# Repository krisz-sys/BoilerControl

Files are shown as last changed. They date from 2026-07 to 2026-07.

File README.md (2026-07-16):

How it works?<br><br>
The ESP8266 runs a web server that displays various data.
The microcontroller turns on the boiler if:

The slider is triggered by the user

The time schedule is active

The user can set the time schedule via the web interface.
The microcontroller reads the value of a DHT11 temperature sensor from port D7 (GPIO13), and the boiler command is handled by port D5 (GPIO14).
The temperature reading is for informational purposes only.

You can access the web server by entering the IP address into your browser: http://192.168.1.223/ . <br>
Additionally, you need to configure the WiFi SSID and password.

You can see the circuit schematic below:



Here is the PCB layout:


<br><br>

You can find the AutoCAD Eagle design files as HeaterController_PCB.

If the web server is live, you should see the following view. The most important elements are the slider, the temperature value, and the time schedule table:
<br>


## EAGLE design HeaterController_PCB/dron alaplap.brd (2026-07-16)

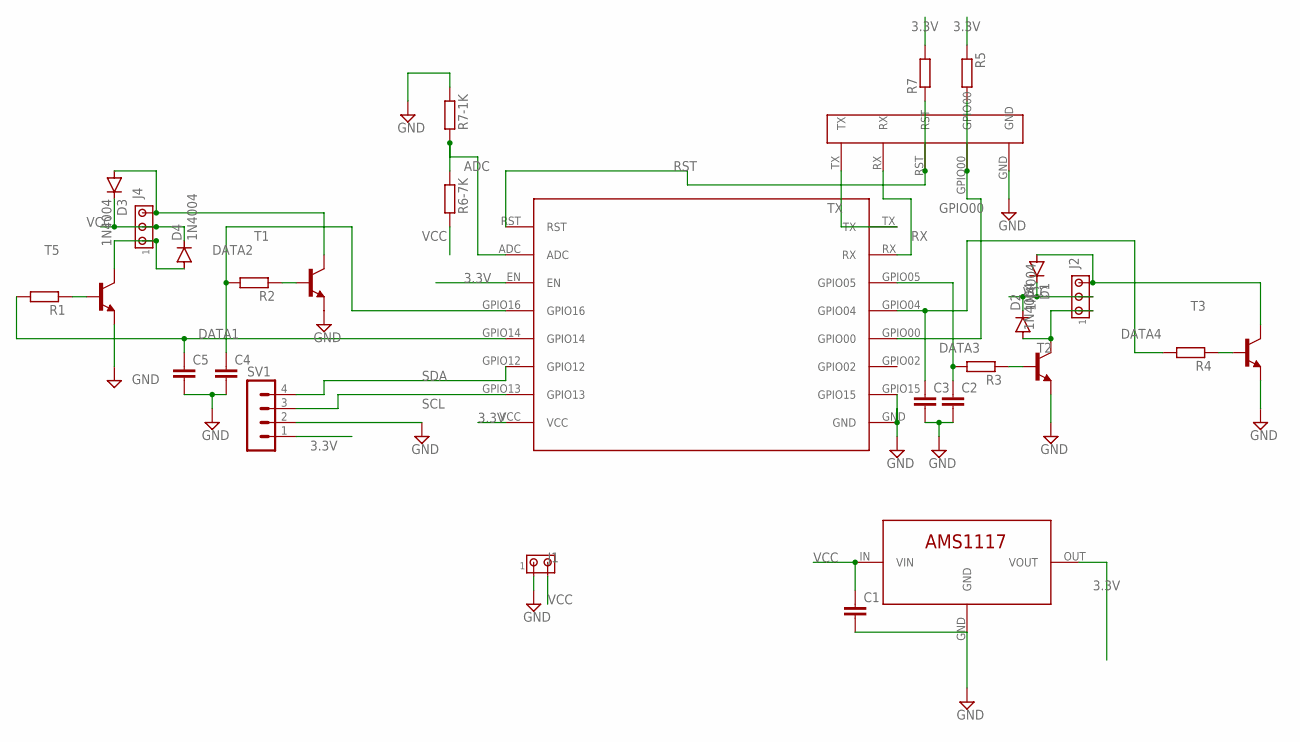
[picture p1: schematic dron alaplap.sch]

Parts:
C1: C-EU025-050X050; C025-050X050
C2, C3, C4: C-EU025-030X050; C025-030X050
C5: C-EU050-025X075; C050-025X075
D1, D2, D3, D4: 1N4004; DO41-10
J1: MTA02-156; 1X2MTA
J2, J4: MTA03-156; 1X3MTA
R1, R2, R3, R4, R5, R6-7K, R7-1K: R-EU_0207/12; 0207/12
R7: R-EU_0207/15; 0207/15
SV1: MA04-1
T1, T2, T3, T5: 2N2222-NPN-TO92-EBC; TO92-EBC
U$1: AMS1117
U$2: ESP8266
U$3: PIN

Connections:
3.3V: R5.1, R7.2, SV1.1, U$1.OUT (VOUT), U$2.EN, U$2.VCC
ADC: R6-7K.1, R7-1K.2, U$2.ADC
DATA1: C5.1, R1.2, U$2.GPIO14
DATA2: C4.1, R2.2, U$2.GPIO16
DATA3: C2.1, R3.2, U$2.GPIO05
DATA4: C3.1, R4.2, U$2.GPIO04
GND: C1.2, C2.2, C3.2, C4.2, C5.2, J1.1, R7-1K.1, SV1.2, T1.E, T2.E, T3.E, T5.E, U$1.GND, U$2.GND, U$2.GPIO15, U$3.GND
GPIO00: R5.2, U$2.GPIO00, U$3.GPIO00
unnamed: D4.A, J4.1, T5.C
unnamed: D2.A, J2.1, T2.C
unnamed: R1.1, T5.B
unnamed: D3.A, J4.3, T1.C
unnamed: R2.1, T1.B
unnamed: R3.1, T2.B
unnamed: D1.A, J2.3, T3.C
unnamed: R4.1, T3.B
RST: R7.1, U$2.RST, U$3.RST
RX: U$2.RX, U$3.RX
SCL: SV1.3, U$2.GPIO13
SDA: SV1.4, U$2.GPIO12
TX: U$2.TX, U$3.TX
VCC: C1.1, D1.C, D2.C, D3.C, D4.C, J1.2, J2.2, J4.2, R6-7K.2, U$1.IN (VIN)

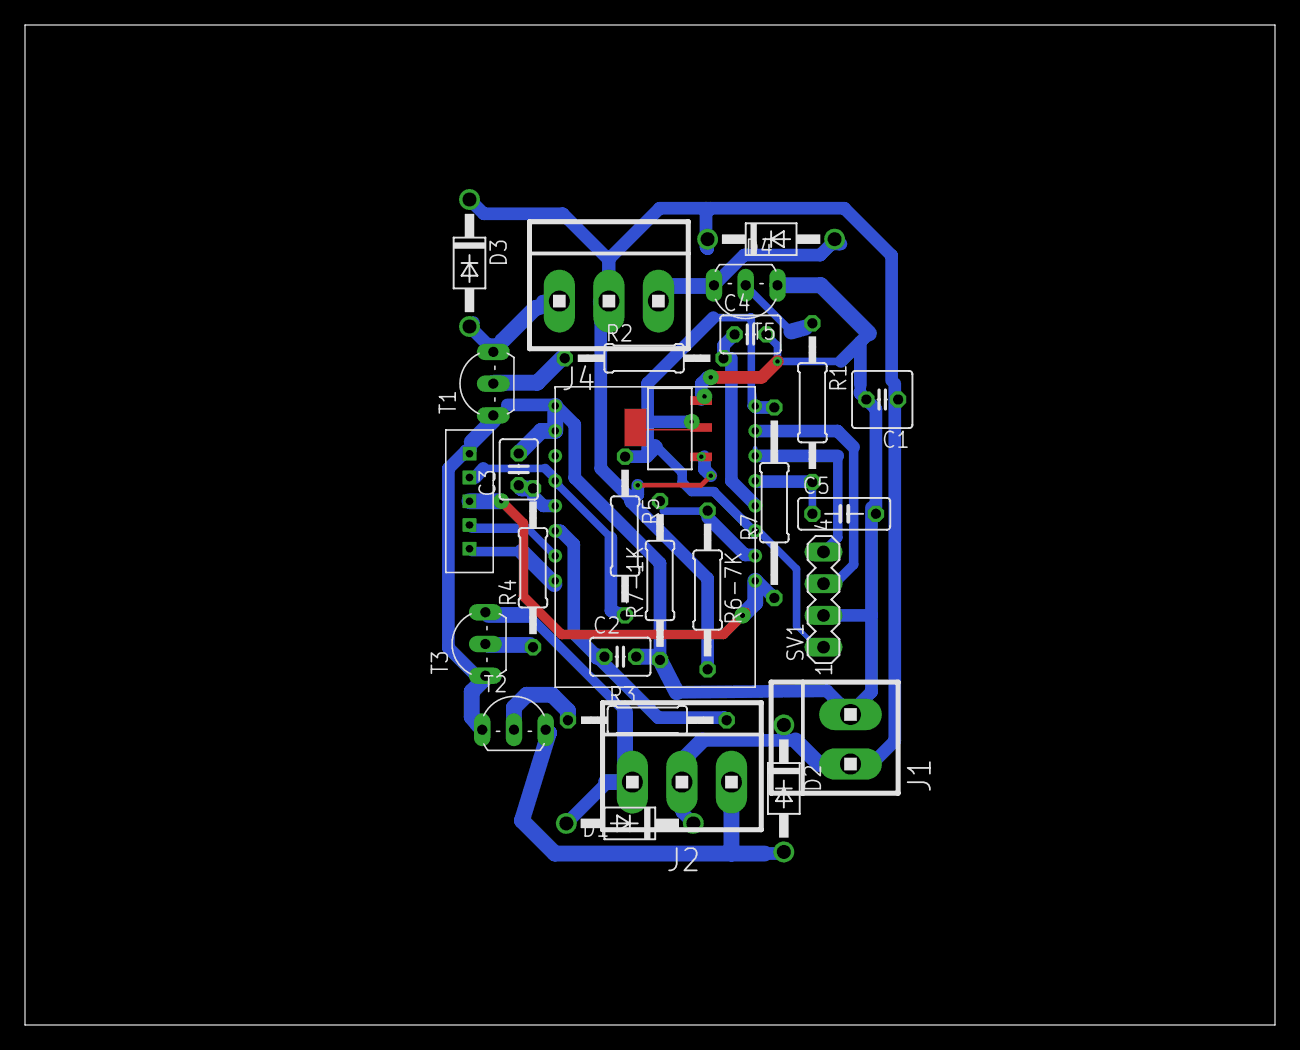
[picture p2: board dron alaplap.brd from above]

Board: 2 copper layers, 100.0 x 80.0 mm, 28 parts (0 on the bottom side), 22 nets.

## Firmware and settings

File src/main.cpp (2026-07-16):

#include <ESP8266WiFi.h>
#include <WiFiUdp.h>
#include <ESP_EEPROM.h>
#include <string.h>
#include <iostream>
#include <sstream>
#include <String.h>
#include "DHT.h"
#include <ArduinoOTA.h>
#include <ESPAsyncWebServer.h>
#include <ESP8266mDNS.h>
#include <time.h>

#include "index.h"
// -------------------------------------- time.h
const char* TZ_INFO = "EET-2EEST,M3.5.0,M10.5.0/3";

// -------------------------------------- NTP server

String formattedDate;
String dayStamp;
String timeStamp;
long date_check_timer;
//--------------------------------------  UDP communication
unsigned int localUdpPort = 9800;
char incomingPacket[255];  // buffer for incoming packets
char respond[255];
char  replyPacket[] = "Hi there! Got the message :-)";  // a reply string to send back
WiFiUDP Udp;
//char* remoteIp="";
String remoteIp="";
//--------------------------------------- temp, humidity 
#define DHTPIN D7              // GPIO13
#define DHTTYPE DHT11
DHT dht(DHTPIN, DHTTYPE);
float humidity=-10;
float temperature=-10;
// --------------------------------------- comm protocol

#define COMM_ERR 56
#define TEMP_REQUEST 39
#define TEMP_FLAG 40
#define HUM_REQUEST 41
#define HUM_FLAG 42
#define TEMP_SENSOR_ERROR 55
#define MSG_RECEIVED 65
//#define SET_LED 66
#define HEATER_ON 60                                  // turn ON theheater for x minutes
#define HEATER_REQUEST 61                             
#define HEATER_REMAINING 62                           // remaining time when the heater is ON
#define HUM_SENSOR_ERR 101                // the humidity sensor is damaged or don t works
#define BOSS 50
#define ADD_TSCH 51
#define ADD_TSCH_CONF 52
#define REMOVE_TSCH 53
#define REMOVE_TSCH_CONF 54
#define REMOVE_TSCH_NCONF 59
#define GET_TSCHS 57
#define SEND_TSCHS 58



//---------------------------------------- Heater
#define HEATER D5                             // GPIO14
//#define HEATER D1                             // GPIO05
bool ledSPMode=true;                       // false => led SP from the POT,       true => led SP from the sender
int lastSample=0;
bool firstStart=true;

//----------------------------------------wifi

//const char *ssid = "BV";          //Enter your wifi SSID
const char *ssid = "yourSSID";
const char *password = "yourPassword";        //Enter your wifi Password
IPAddress local_IP(192, 168, 1, 223);       // a telefonba ezt az ip-t kell beírni
//IPAddress local_IP(192, 168, 1, 223);
IPAddress gateway(192, 168, 1,1);
IPAddress subnet(255, 255, 255, 0);
IPAddress primaryDNS(8, 8, 8, 8);           //optional
IPAddress secondaryDNS(8, 8, 4, 4);

#define debug(x) Serial.print(x)
#define debugln(x) Serial.println(x)

long reconnect_period=120*1000;
long reconnectTimer;
long universalTimer;                        // call the other functionalitys every 100 ms

long testTimer;

long heaterCounter=0;                           // counts down every 3000ms until 0
long heaterTimer;
long heaterHandlerPeriod=3000;
long tempSamplePeriod=30000;

int TSCH_array[20][3];
int TSCH_len=0;
int currentTime=0;           // current time in minutes
long checkTSCHTimer;
long  tempSampleTimer;

AsyncWebServer server1(80);
AsyncWebSocket ws("/ws");  // WebSocket endpoint

// Function to send value updates to clients
void notifyClients(int heaterVal, float temp) {

  String finalString=String(heaterVal)+", "+String(temperature,1);

  for(int i=0;i<3;++i){
    finalString+=", ";
    int hour=TSCH_array[i][0];
    int min=TSCH_array[i][1];
    int time=TSCH_array[i][2];
    
    if(hour<10){
      finalString+="0";
    }
    finalString+=String(hour)+":";
    if(min<10){
      finalString+="0";
    }
    finalString+=String(min)+", "+String(time);
  }
  
  ws.textAll(finalString);  // send value to all connected clients
}

// Handle incoming WebSocket messages (optional)
void onWebSocketMessage(void *arg, uint8_t *data, size_t len) {
  AwsFrameInfo *info = (AwsFrameInfo*)arg;

  if (info->final && info->index == 0 && info->opcode == WS_TEXT) {

    // Safe copy
    char message[len + 1];
    memcpy(message, data, len);
    message[len] = 0;

    String msg = String(message);
    Serial.println("Received: " + msg);

    // Expecting message like: "Slider: 234"
    String prefix = "Slider: ";
    if (msg.startsWith(prefix)) {
      String sliderVal = msg.substring(prefix.length());

      heaterCounter = sliderVal.toInt();
      if (heaterCounter > 0) {
        digitalWrite(HEATER, HIGH);
      }

      Serial.println("Parsed slider value: " + sliderVal);
    }

    prefix = "Button: ";

    if (msg.startsWith(prefix)) {
      String buttonVal = msg.substring(prefix.length());
      Serial.println("Button value: " + buttonVal);
    }


    
    if(msg.startsWith("TS") && msg.charAt(4)=='T'){
        prefix=msg.substring(0,7);
        int index=int(msg.charAt(2)-'0')-1;

      if (msg.startsWith(prefix)) {
        String TS1_Tval = msg.substring(prefix.length());
        int time=atoi(TS1_Tval.c_str());
        TSCH_array[index][2]=time;
        EEPROM.write(index*3+3, TSCH_array[index][2]);
        EEPROM.commit();
      }
    }
    

    if(msg.startsWith("TS") && msg.charAt(4)=='H'){
      prefix=msg.substring(0,7);
      int index=int(msg.charAt(2)-'0')-1;

      if (msg.startsWith(prefix)) {
        String TS1_Hval = msg.substring(prefix.length());
        String hour=TS1_Hval.substring(0,2);
        String minute=TS1_Hval.substring(3,5);

        TSCH_array[index][0]=atoi(hour.c_str());
        TSCH_array[index][1]=atoi(minute.c_str());
        EEPROM.write(index*3+1, TSCH_array[index][0]);
        EEPROM.write(index*3+2, TSCH_array[index][1]);
        EEPROM.commit();
      }
    }


  }
}

void onWebSocketEvent(AsyncWebSocket *server, AsyncWebSocketClient *client, 
                      AwsEventType type, void *arg, uint8_t *data, size_t len) {
  if (type == WS_EVT_CONNECT) {
    Serial.printf("Client #%u connected\n", client->id());
  } else if (type == WS_EVT_DISCONNECT) {
    Serial.printf("Client #%u disconnected\n", client->id());
  } else if (type == WS_EVT_DATA) {
    onWebSocketMessage(arg, data, len);
  }
}

String sliderValue = "0";
bool startMeasuring=false;


void connect2Wifi(int);
int receiveUDP();
void decodeAndBuildRespond();
void getTime();
int receiveUDP();
void sendUDP();
void readHumAndTemp();
bool temp2bytes(char*);
void turnON(int);
String processor(const String& var);
void temp1Request(AsyncWebServerRequest *request);
void sliderRequest(AsyncWebServerRequest *request);

void setup() {
  EEPROM.begin(512);
  Serial.begin(115200);
  
  dht.begin();
  pinMode(HEATER,OUTPUT);


  if (!WiFi.config(local_IP, gateway, subnet, primaryDNS, secondaryDNS)) {
    Serial.println("STA Failed to configure");
  }
  
  Serial.printf("Connecting to %s ", ssid);
  WiFi.mode(WIFI_STA);
  WiFi.begin(ssid, password); //Connect to wifi
  //WiFi.begin(ssid); //Connect to wifi
  connect2Wifi(200);

  Udp.begin(localUdpPort);

  reconnectTimer=millis();
  date_check_timer=millis();
  universalTimer=millis();
  heaterTimer=millis();
  checkTSCHTimer=millis();
  testTimer=millis();
  tempSampleTimer=millis();

  
  //TSCH_len=EEPROM.read(0);
  TSCH_len=4;
  for(int i=0;i<TSCH_len;++i){
    TSCH_array[i][0]=EEPROM.read(i*3+1);
    TSCH_array[i][1]=EEPROM.read(i*3+2);
    TSCH_array[i][2]=EEPROM.read(i*3+3);
  }
  // ---------------------------------- webserver

  server1.on("/", HTTP_GET, [](AsyncWebServerRequest *request){
    request->send_P(200, "text/html; charset=utf-8",index_html);
  });
  ws.onEvent(onWebSocketEvent);
  server1.addHandler(&ws);
  server1.begin();

    //---------------------------------- OTA

// Port defaults to 8266
  // ArduinoOTA.setPort(8266);

  // Hostname defaults to esp8266-[ChipID]
   ArduinoOTA.setHostname("ESP8266-Boiler controller");

  // No authentication by default
  ArduinoOTA.setPassword("admin");

  // Password can be set with it's md5 value as well
  // MD5(admin) = 21232f297a57a5a743894a0e4a801fc3
  // ArduinoOTA.setPasswordHash("21232f297a57a5a743894a0e4a801fc3");

  ArduinoOTA.onStart([]() {
    String type;
    if (ArduinoOTA.getCommand() == U_FLASH) {
      type = "sketch";
    } else {  // U_FS
      type = "filesystem";
    }

    // NOTE: if updating FS this would be the place to unmount FS using FS.end()
    Serial.println("Start updating " + type);
  });
  ArduinoOTA.onEnd([]() {
    Serial.println("\nEnd");
  });
  ArduinoOTA.onProgress([](unsigned int progress, unsigned int total) {
    Serial.printf("Progress: %u%%\r", (progress / (total / 100)));
  });
  ArduinoOTA.onError([](ota_error_t error) {
    Serial.printf("Error[%u]: ", error);
    if (error == OTA_AUTH_ERROR) {
      Serial.println("Auth Failed");
    } else if (error == OTA_BEGIN_ERROR) {
      Serial.println("Begin Failed");
    } else if (error == OTA_CONNECT_ERROR) {
      Serial.println("Connect Failed");
    } else if (error == OTA_RECEIVE_ERROR) {
      Serial.println("Receive Failed");
    } else if (error == OTA_END_ERROR) {
      Serial.println("End Failed");
    }
  });
  ArduinoOTA.begin();

  if (MDNS.begin("boilercontrol")) {
    Serial.println("mDNS responder started");
  }

  // ------------------ time.h

  configTime(0, 0, "pool.ntp.org", "time.nist.gov");
  
  // Időzóna érvényesítése
  setenv("TZ", TZ_INFO, 1);
  tzset();
}


String processor(const String& var){
  //Serial.println(var);
  if (var == "SLIDERVALUE"){
    return sliderValue;
  }
  return String();
}

void temp1Request(AsyncWebServerRequest *request){
      startMeasuring=true;
      //readHumAndTemp();
      request->send(200, "text/plain", String(temperature,1));          // sends with precision 1
}

void sliderRequest(AsyncWebServerRequest *request) {
  request->send(200, "text/plain", String(heaterCounter,0));
    
  }



void checkTSCH(){
  for(int i=0;i<TSCH_len;++i){
    int targetTime=60*((int)TSCH_array[i][0])+(int)TSCH_array[i][1];            // calculating the minutes => hours*60+minutes
    if(targetTime==currentTime){                                                // starting 
      turnON((int)TSCH_array[i][2]);
      debug("match: ");
      debugln(heaterCounter);
    }
  }
}

void heaterHandler(){

  if(heaterCounter>=0){
    heaterCounter--;
  }
  if(heaterCounter<0){
    digitalWrite(HEATER,0);
  }
}

void connect2Wifi(int max_attempts){
  int i=0;
  while (WiFi.status() != WL_CONNECTED)
  {
    delay(50);
    Serial.print(".");
    if(i>=max_attempts){
      break;
    }
    i++;
  }
  debugln("");
  debug("localIP: ");
  debugln(WiFi.localIP());
}


void decodeAndBuildRespond(){
  //debugln("decoding: ");
  for(int i=1;i<(int)incomingPacket[0];++i){
    debug((int)incomingPacket[i]);
    debug(" ");
  }
  //debugln("");
  int i=0;                    // counter of the receiver packet
  int j=1;              // counter of the respond packet
  int len=incomingPacket[i++];
  //char respond[50];
  //debug("len: ");
  //debugln(len);
  while(1){
    if(i>=len){
      break;
    }
    byte b=(byte)incomingPacket[i++];
    //debugln(b);
    if(b==TEMP_REQUEST){
      readHumAndTemp();
      char tempbytes[2];
      respond[j++]=TEMP_FLAG;
      if(temp2bytes(tempbytes)){
        respond[j++]=tempbytes[0];
        respond[j++]=tempbytes[1];
      }
      else{
        respond[j++]=TEMP_SENSOR_ERROR;
        respond[j++]=TEMP_SENSOR_ERROR;
      }
    }
    if(b==HUM_REQUEST){
      readHumAndTemp();
      respond[j++]=HUM_FLAG;
      if(humidity!=-10){
        respond[j++]=humidity;
      }
      else{
        respond[j++]=HUM_SENSOR_ERR;
      }
    }
    if(b==HEATER_ON){
      //heaterCounter=incomingPacket[i++];
      turnON(((int)incomingPacket[i++])-1);
      if(heaterCounter<=1){
        heaterCounter=0;
        digitalWrite(HEATER,0);
      }

    }
    if(b==HEATER_REQUEST){
      respond[j++]=HEATER_REMAINING;
      respond[j++]=(byte)(heaterCounter/(60000/heaterHandlerPeriod)+1);
    }
    if(b==ADD_TSCH){
      TSCH_array[TSCH_len][0]=(int)(incomingPacket[i++])-1;
      TSCH_array[TSCH_len][1]=(int)(incomingPacket[i++])-1;
      TSCH_array[TSCH_len][2]=(int)(incomingPacket[i++])-1;
      EEPROM.write(TSCH_len*3+1, TSCH_array[TSCH_len][0]);
      EEPROM.write(TSCH_len*3+2, TSCH_array[TSCH_len][1]);
      EEPROM.write(TSCH_len*3+3, TSCH_array[TSCH_len][2]);
      TSCH_len++;
      EEPROM.write(0, TSCH_len);
      EEPROM.commit();
      respond[j++]=ADD_TSCH_CONF;
    }
    if(b==REMOVE_TSCH){
      int index=(int)incomingPacket[i++]-1;
      if(index>=0 && index<TSCH_len){
        respond[j++]=REMOVE_TSCH_CONF;
        for (int k=index;k<TSCH_len-1;++k){
          TSCH_array[k][0]=TSCH_array[k+1][0];
          TSCH_array[k][1]=TSCH_array[k+1][1];
          TSCH_array[k][2]=TSCH_array[k+1][2];
          EEPROM.write(k*3+1,TSCH_array[k][0]);
          EEPROM.write(k*3+2,TSCH_array[k][1]);
          EEPROM.write(k*3+3,TSCH_array[k][2]);
        }
        TSCH_len--;
        EEPROM.write(0, TSCH_len);
        EEPROM.commit();
      }
      else{
        respond[j++]=REMOVE_TSCH_NCONF;
      }
    }
    if(b==GET_TSCHS){
      respond[j++]=SEND_TSCHS;
      respond[j++]=TSCH_len+1;
      for (int k=0;k<TSCH_len;++k){
          respond[j++]=TSCH_array[k][0]+1;
          respond[j++]=TSCH_array[k][1]+1;
          respond[j++]=TSCH_array[k][2]+1;
       }
    }
    
  }
  if(j==1){
    respond[j++]=MSG_RECEIVED;
  }
  respond[j]='\0';
  respond[0]=j-1;
  delay(1);                         // without this delay the controller doesn t send back the msg properly
  incomingPacket[0]=0;
  //return respond;
}

void getTime(){

  time_t now = time(nullptr);         // get the current time
  struct tm* p_tm = localtime(&now);  // convert to local time


  currentTime=p_tm->tm_hour*60+p_tm->tm_min;


}

int receiveUDP(){
  int packetSize = Udp.parsePacket();
  if (packetSize)
  {
    // receive incoming UDP packets
    //Serial.printf("Received %d bytes from %s, port %d\n", packetSize, Udp.remoteIP().toString().c_str(), Udp.remotePort());
    //const char* cRemIP=Udp.remoteIP().toString().c_str();
    //remoteIp=Udp.remoteIP();
    //const char* cRemIP=Udp.remoteIP();
    //debugln(typeid(Udp.remoteIP()).name());
    //strcpy(remoteIp,cRemIP);
    int len = Udp.read(incomingPacket, 255);
    debugln(len);
    debugln((int)incomingPacket[1]);
    if((int)incomingPacket[1]!=BOSS){
        return 0;
    }
    if (len > 0)
    {
      incomingPacket[len] = 0;
    }
    //Serial.printf("UDP packet contents: %s\n", incomingPacket);
  }
  return packetSize;
}



void sendUDP(){
    Udp.beginPacket(Udp.remoteIP(), localUdpPort);
    Udp.write(respond);
    Udp.endPacket();  


    debugln("");
    debug("Respond:  ");
    for(int i=0;i<strlen(respond);++i){
      debug((byte)respond[i]);
      debug(" ");
    }
    debugln("");
/*
    Serial.print(Udp.remoteIP());
    Serial.print(" ");
    Serial.println(Udp.remotePort());
  */  
}


/*
void sendUDP(char *msg,char* ip){  
    Udp.beginPacket(ip, localUdpPort);
    Udp.write(msg);
    Udp.endPacket();
}
*/

void readHumAndTemp(){
  //long startTime=millis();
  humidity = dht.readHumidity();
  float temp= dht.readTemperature();
  //temperature = dht.computeHeatIndex(temp, humidity, false);
  temperature=temp;
  //startTime=millis()-startTime;
  //debug("measure time: ");
  //debugln(startTime);
  if(isnan(humidity)){
    humidity=-10;
  }
  if(isnan(temperature)){
    temperature=-10;
  }
}

bool temp2bytes(char*tempBytes){
  if(temperature!=-10){
    double fractpart, intpart; 
    fractpart = modf (temperature , &intpart);
    tempBytes[0]=(char)intpart;
    tempBytes[1]=(char)(fractpart*100);
    return true;
  }
  return false;
}

void turnON(int minutes){
    digitalWrite(HEATER,1);
    heaterCounter=minutes*60000/heaterHandlerPeriod;
}



void loop() {
  ArduinoOTA.handle();

  /*
    if(receiveUDP()>0){
    debug("received: ");
    //char*respond=decodeAndBuildRespond();
    decodeAndBuildRespond();
    delay(100);
    //sendUDP(remoteIp);
    sendUDP();
  }
  */

    

  if(millis()-universalTimer>1000){
    universalTimer=millis();

    if(millis()-reconnectTimer>reconnect_period){
      reconnectTimer=millis();
      connect2Wifi(200);
    }
    if(millis()-date_check_timer>60000){
      getTime();
      checkTSCH();
      if(strcmp(timeStamp.c_str(),"04:00")==0 || strcmp(timeStamp.c_str(),"16:00")==0){
        debugln("restarting");
        ESP.restart();
      }
      date_check_timer=millis();
    }
    if(millis()-heaterTimer>heaterHandlerPeriod){
      heaterHandler();
      heaterTimer=millis();
    }
    if(millis()-tempSampleTimer>tempSamplePeriod){
        //if(startMeasuring==true){
            tempSampleTimer=millis();
            readHumAndTemp();
            startMeasuring=false;
          //}
      }
    notifyClients(heaterCounter, temperature);
   }
   
  
}

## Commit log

2026-07-16 PCB added
    [dron alaplap.brd, dron alaplap.sch]
2026-07-16 PCB update
    [dron alaplap.sch]
